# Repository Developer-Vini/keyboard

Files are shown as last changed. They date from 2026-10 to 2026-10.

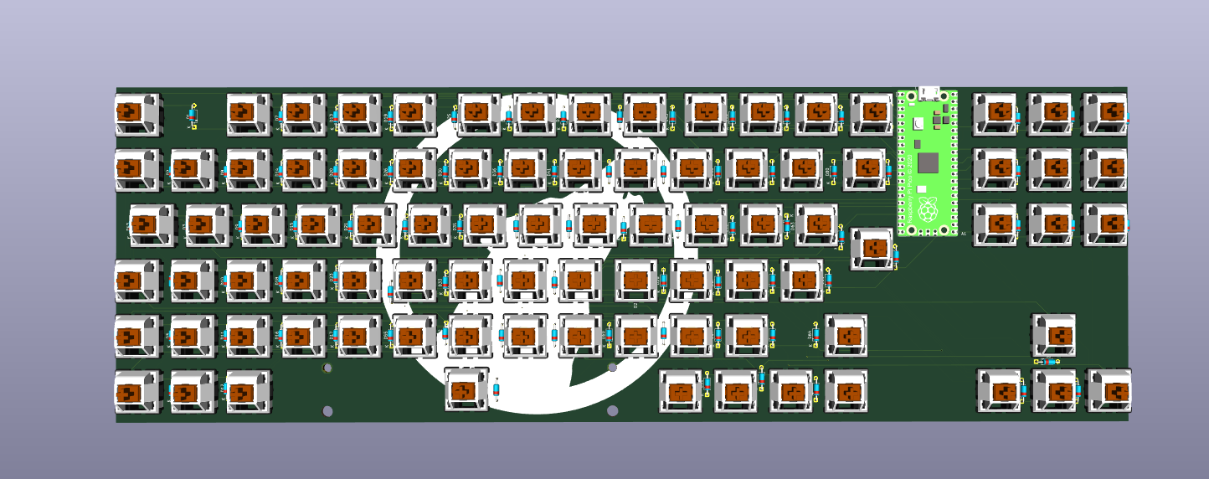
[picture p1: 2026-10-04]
docs/Images/front_pcb.png

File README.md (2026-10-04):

# Keyboard

This project is a 75% mechanical keyboard that I developed from scratch using KiCad. The idea was to create a compact, functional, and relatively simple keyboard, retaining the main keys of a conventional keyboard without taking up too much desk space.
The project was designed to be a real physical keyboard, so I didn't just focus on the visual aspect: I developed the circuit board (PCB), organized the key matrix, defined the electrical connections, and chose the necessary components so that the keyboard can be assembled and used later.

This project was going to be submitted to the Fabricate program, but I decided against it; I'll post it here instead. Because I thought halfway through, I have several other things to do, it's better not to. I didn't end up submitting it!

# Layout 
The keyboard uses a 75% layout, which retains virtually all the important functions of a full keyboard, but eliminates the spacebar and some less frequently used keys.
It has the main letter, number, and symbol keys, as well as keys such as the arrow keys, Shift, Ctrl, Alt, Enter, Backspace, and other function keys.


front_pcb

# PCB

The entire board was designed in KiCad. First, I arranged the keys according to the chosen layout and then started working on the electrical part.
The keys are part of a matrix of rows and columns. This way, it's not necessary to connect each key directly to a separate microcontroller pin. Each switch is connected to the matrix, allowing the microcontroller to identify which key was pressed.
I also added the components necessary for the correct reading of the matrix, including the diodes associated with the keys.

back_pcb
front_pcb
pcb_editor

# Scheme
general_scheme
matrix
mx_stap
raspberrypi

# Microcontroller
The keyboard has a microcontroller responsible for reading the key matrix and transforming the keystrokes into commands that the computer can interpret.


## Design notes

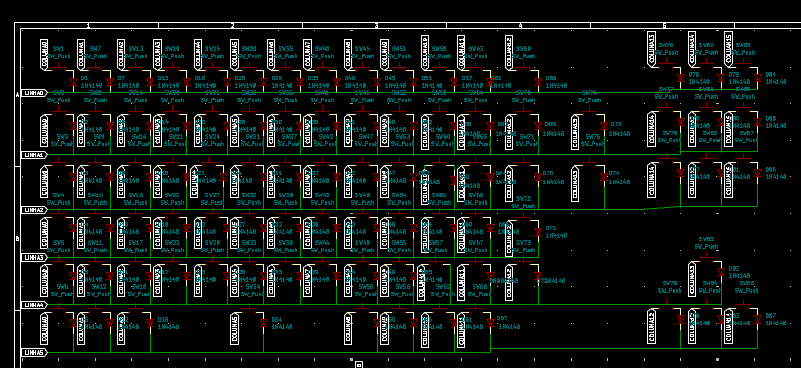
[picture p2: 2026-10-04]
docs/Images/matrix.png

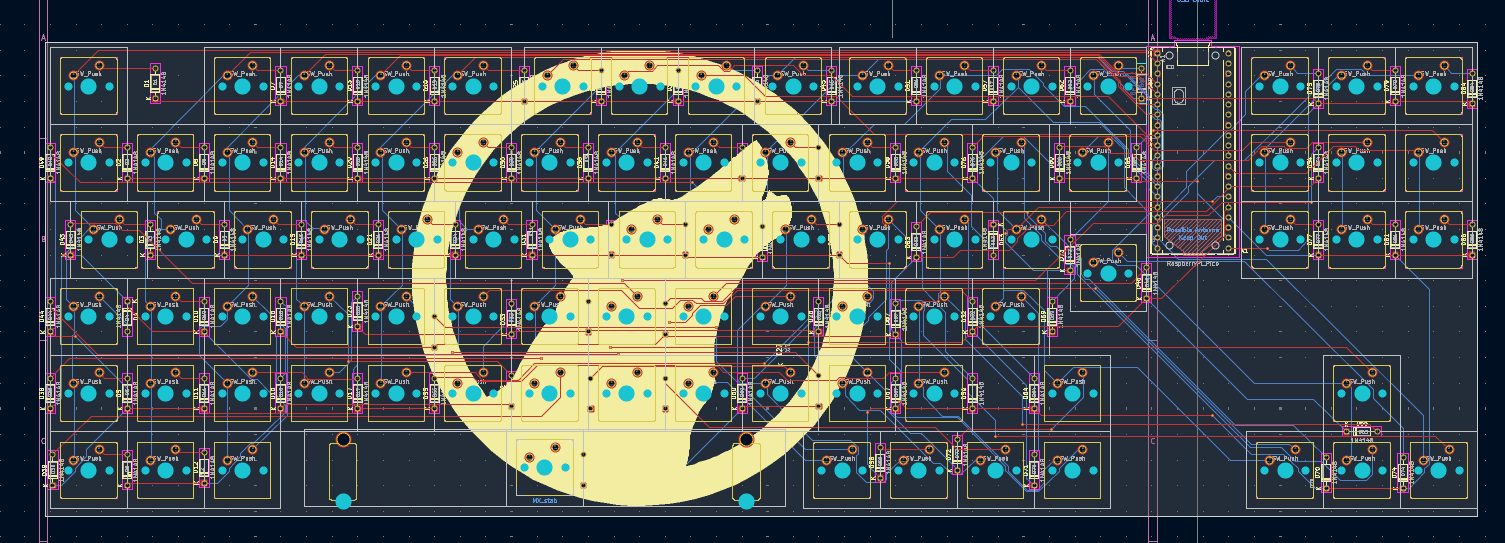
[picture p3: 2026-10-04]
docs/Images/pcb_editor.png

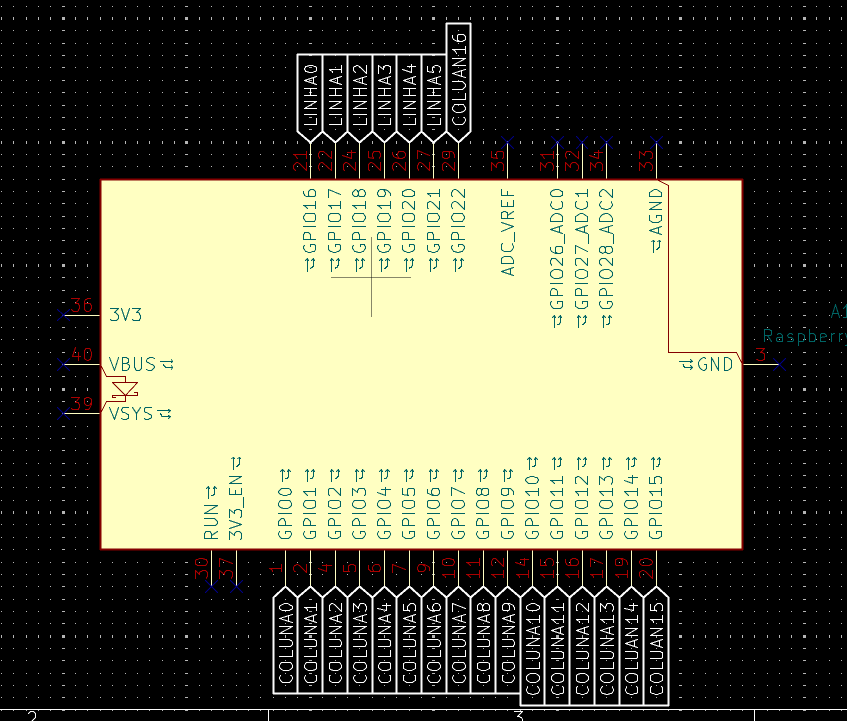
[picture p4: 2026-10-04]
docs/Images/raspberrypi.png

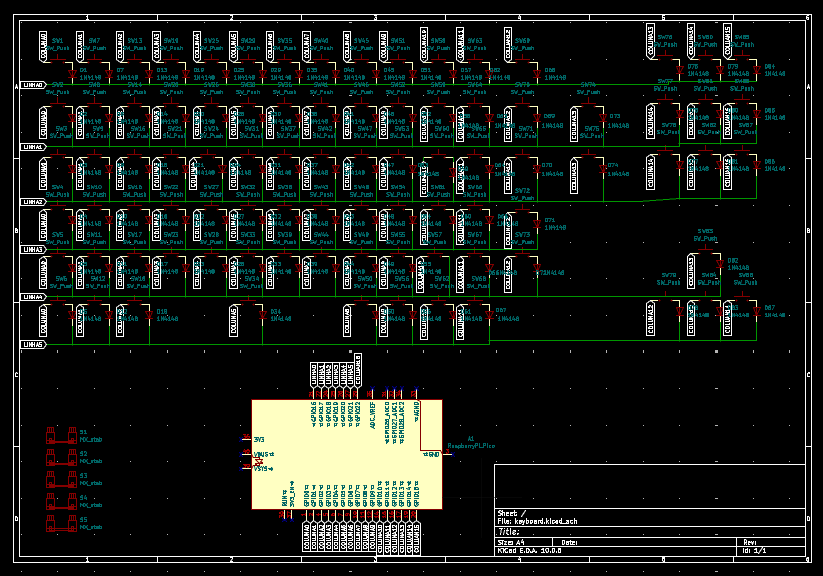
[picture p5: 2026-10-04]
docs/Images/general_scheme.png

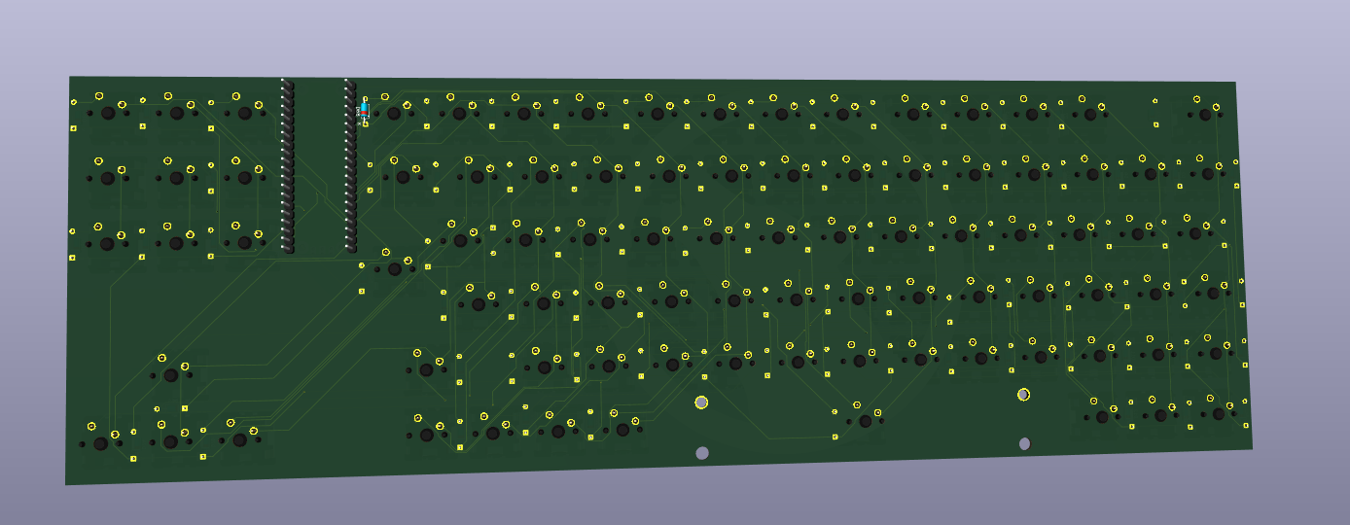
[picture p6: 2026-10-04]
docs/Images/back_pcb.png

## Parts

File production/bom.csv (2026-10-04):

Designator | Footprint | Quantity | Value | LCSC Part #
A1 | RaspberryPi_Pico_Common_THT | 1 | RaspberryPi_Pico
D1, D10, D11, D12, D13, D14, D15, D16, D17, D18, D19, D2, D20, D21, D22, D23, D24, D25, D26, D27, D28, D29, D3, D30, D31, D32, D33, D34, D35, D36, D37, D38, D39, D4, D40, D41, D42, D43, D44, D45, D46, D47, D48, D49, D5, D50, D51, D52, D53, D54, D55, D56, D57, D58, D59, D6, D60, D61, D62, D63, D64, D65, D66, D67, D68, D69, D7, D70, D71, D72, D73, D74, D75, D76, D77, D78, D79, D8, D80, D81, D82, D83, D84, D85, D86, D87, D9 | D_DO-35_SOD27_P7.62mm_Horizontal | 87 | 1N4148
S3 | STAB_MX_P_6.25u | 1 | MX_stab
SW1, SW10, SW11, SW12, SW13, SW14, SW15, SW16, SW17, SW18, SW19, SW2, SW20, SW21, SW22, SW23, SW24, SW25, SW26, SW27, SW28, SW29, SW3, SW30, SW31, SW32, SW33, SW34, SW35, SW36, SW37, SW38, SW39, SW4, SW40, SW41, SW42, SW43, SW44, SW45, SW46, SW47, SW48, SW49, SW5, SW50, SW51, SW52, SW53, SW54, SW55, SW56, SW57, SW58, SW59, SW6, SW60, SW61, SW62, SW63, SW64, SW65, SW66, SW67, SW68, SW69, SW7, SW70, SW71, SW72, SW73, SW74, SW75, SW76, SW77, SW78, SW79, SW8, SW80, SW81, SW82, SW83, SW84, SW85, SW86, SW87, SW88, SW9 | SW_MX_1u | 88 | SW_Push

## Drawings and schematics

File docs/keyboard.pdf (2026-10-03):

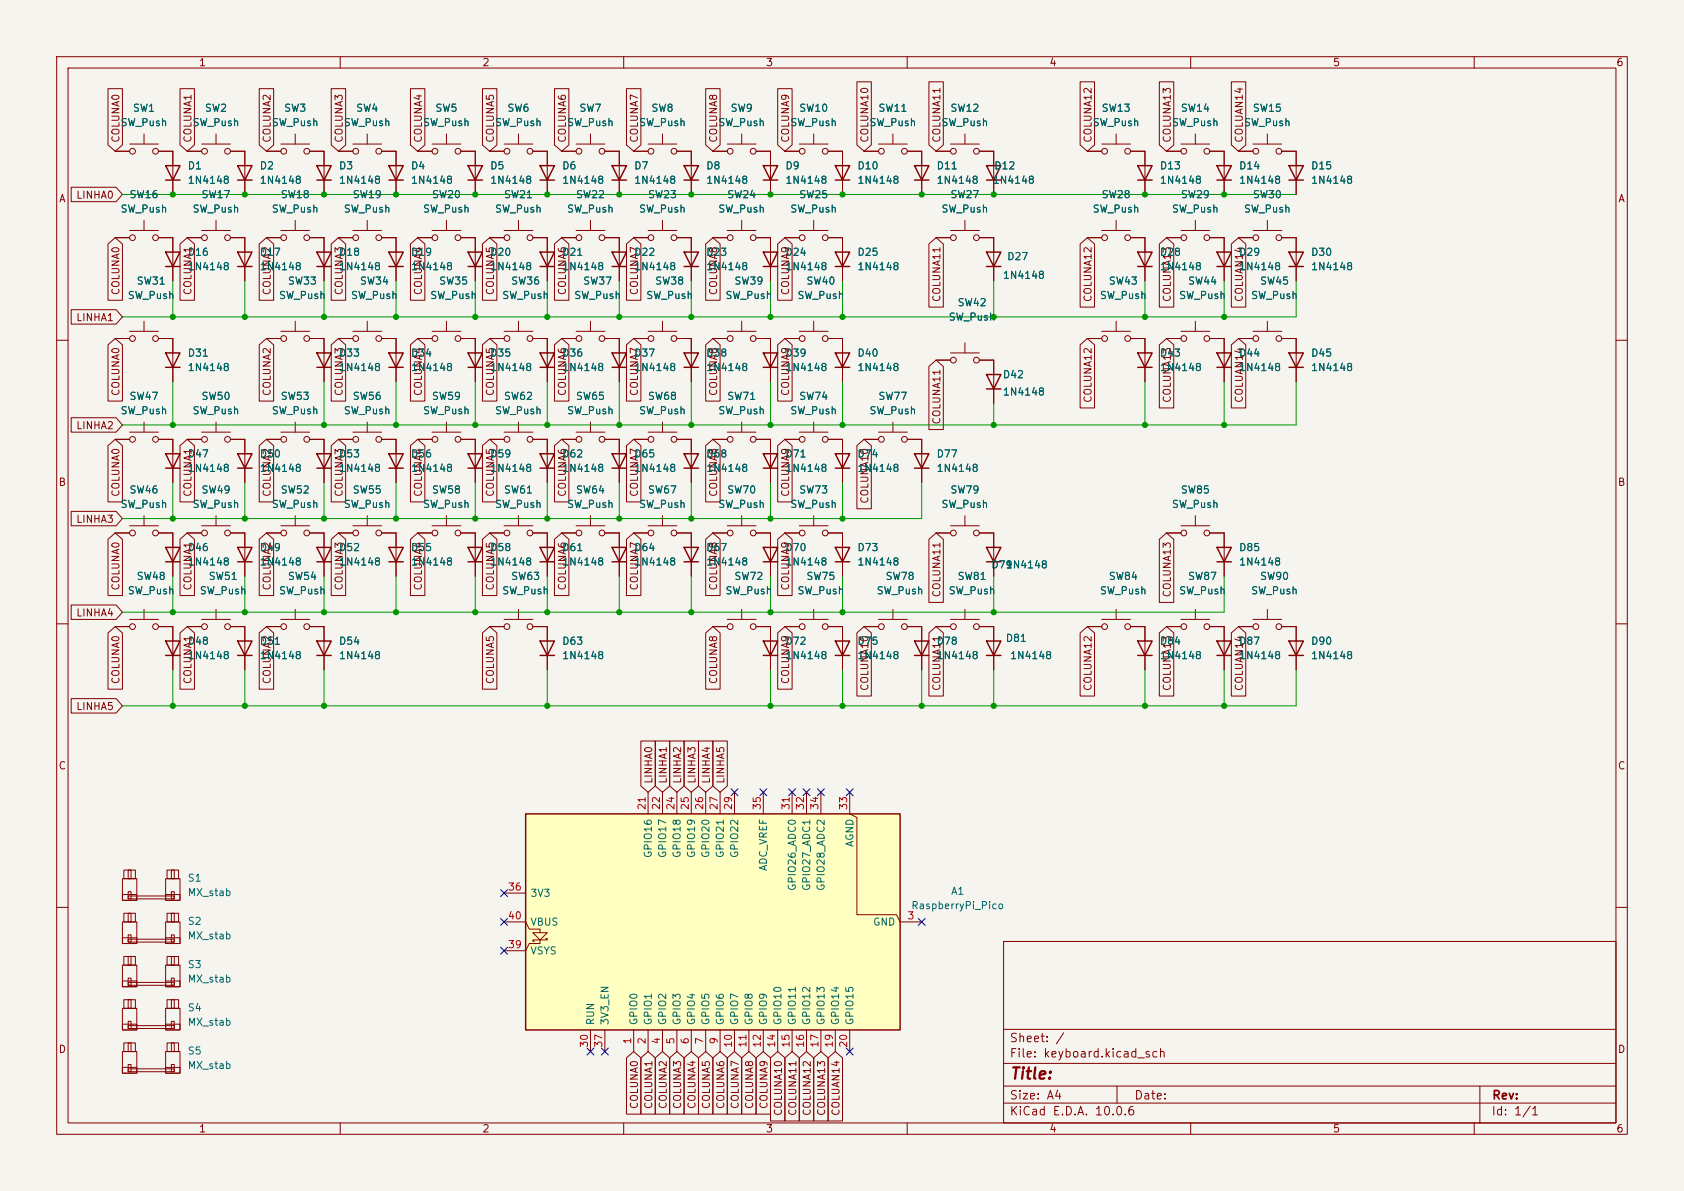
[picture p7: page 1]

Size: A4 | Rev:
KiCad E.D.A. 10.0.6 | Id: 1/1

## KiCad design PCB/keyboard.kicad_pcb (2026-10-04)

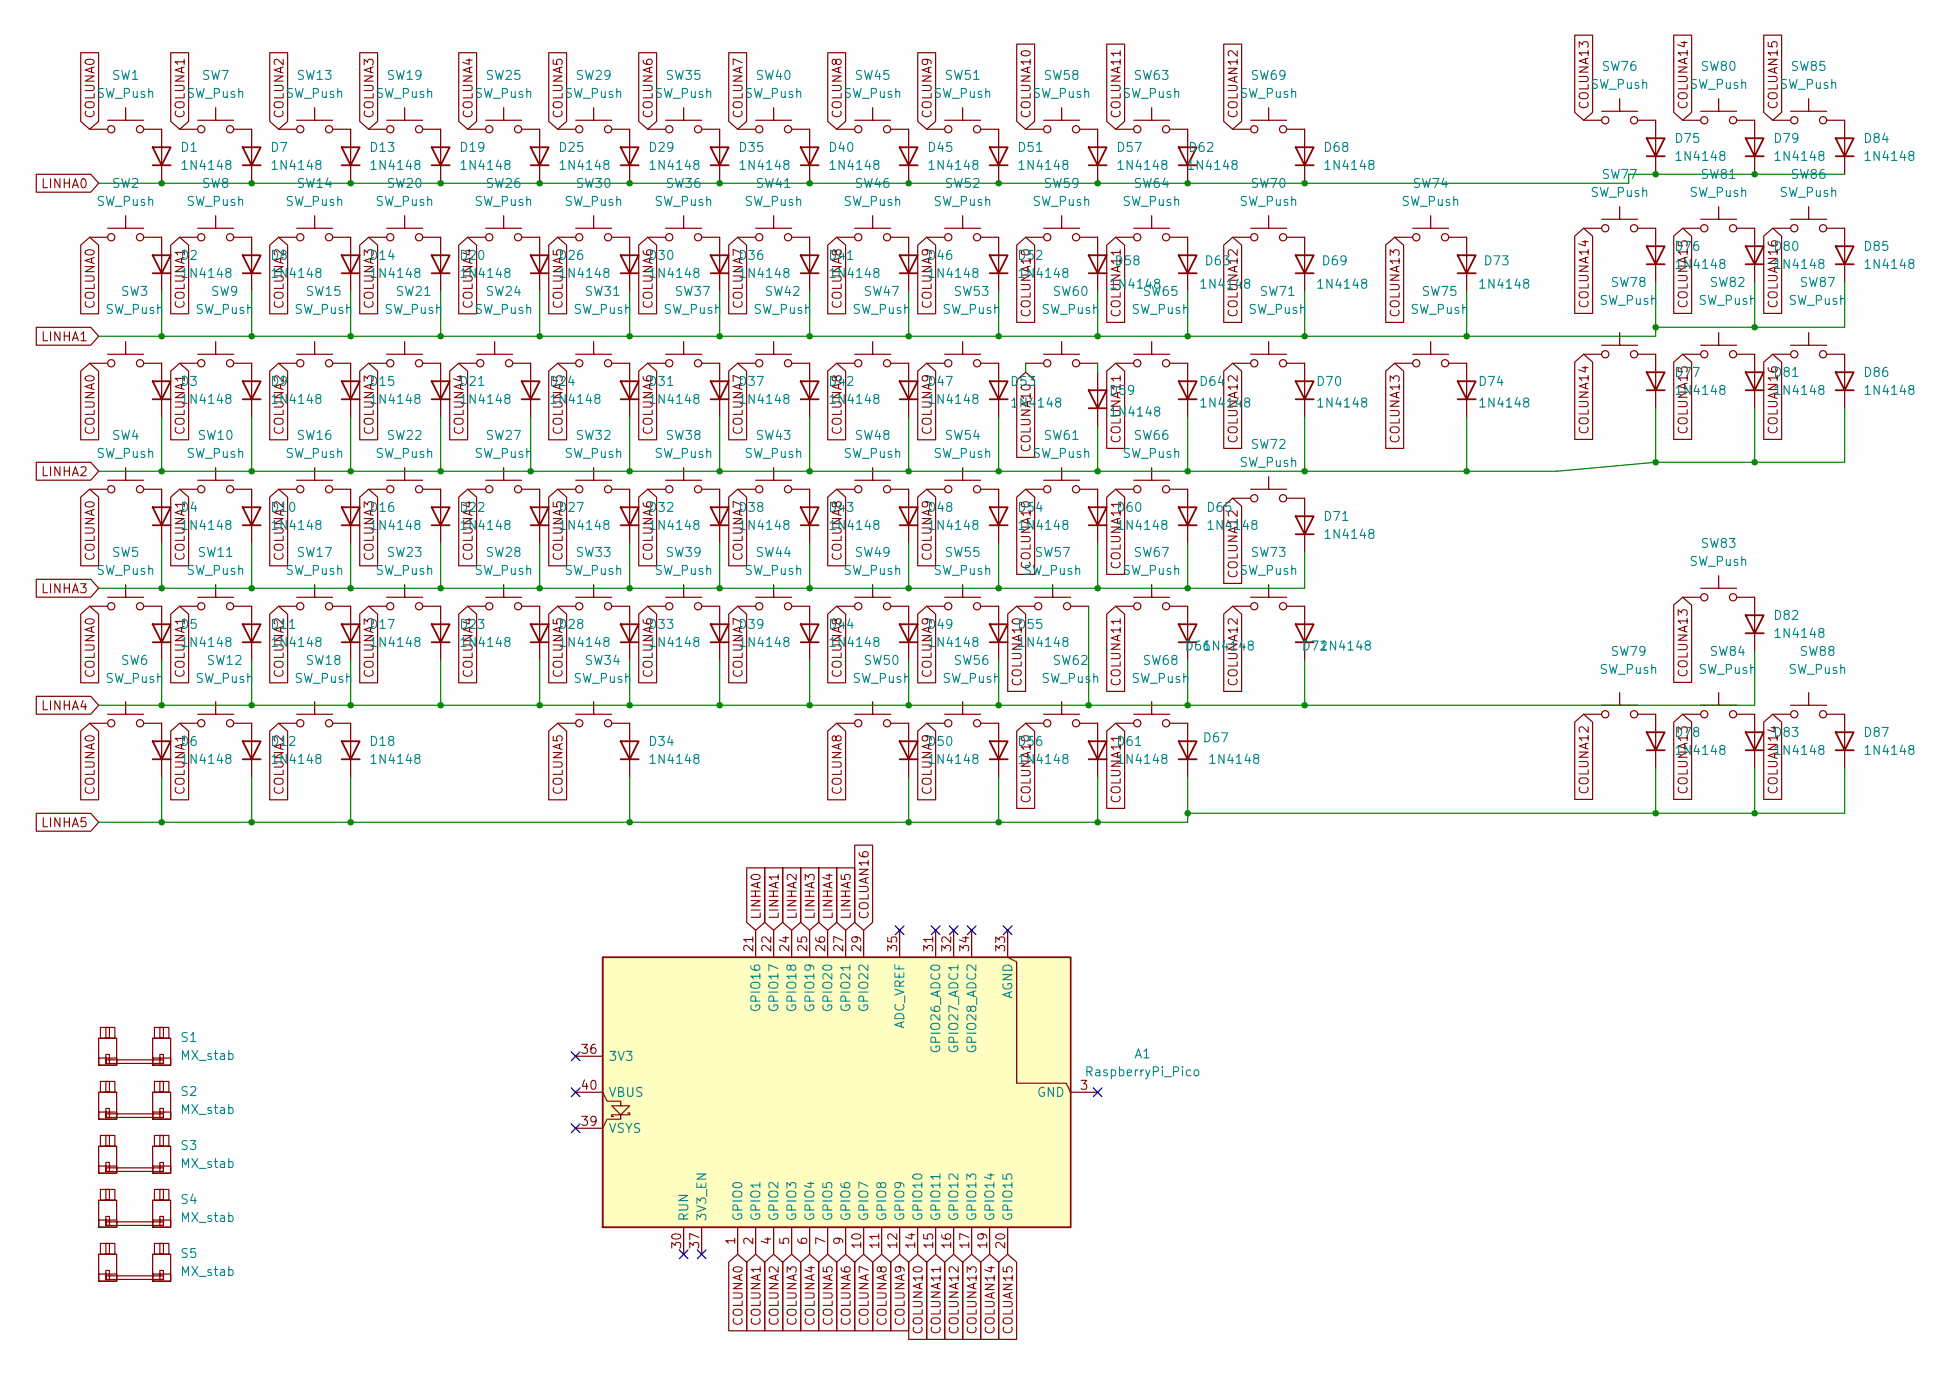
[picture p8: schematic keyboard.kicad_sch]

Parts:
A1: RaspberryPi_Pico; RaspberryPi_Pico_Common_THT
D1, D2, D3, D4, D5, D6, D7, D8, D9, D10, D11, D12, D13, D14, D15, D16, D17, D18, D19, D20, D21, D22, D23, D24, D25, D26, D27, D28, D29, D30, D31, D32, D33, D34, D35, D36, D37, D38, D39, D40, D41, D42, D43, D44, D45, D46, D47, D48, D49, D50, D51, D52, D53, D54, D55, D56, D57, D58, D59, D60, D61, D62, D63, D64, D65, D66, D67, D68, D69, D70, D71, D72, D73, D74, D75, D76, D77, D78, D79, D80, D81, D82, D83, D84, D85, D86, D87: 1N4148; D_DO-35_SOD27_P7.62mm_Horizontal
S1, S2, S3, S4, S5: MX_stab; STAB_MX_P_6.25u
SW1, SW2, SW3, SW4, SW5, SW6, SW7, SW8, SW9, SW10, SW11, SW12, SW13, SW14, SW15, SW16, SW17, SW18, SW19, SW20, SW21, SW22, SW23, SW24, SW25, SW26, SW27, SW28, SW29, SW30, SW31, SW32, SW33, SW34, SW35, SW36, SW37, SW38, SW39, SW40, SW41, SW42, SW43, SW44, SW45, SW46, SW47, SW48, SW49, SW50, SW51, SW52, SW53, SW54, SW55, SW56, SW57, SW58, SW59, SW60, SW61, SW62, SW63, SW64, SW65, SW66, SW67, SW68, SW69, SW70, SW71, SW72, SW73, SW74, SW75, SW76, SW77, SW78, SW79, SW80, SW81, SW82, SW83, SW84, SW85, SW86, SW87, SW88: SW_Push; SW_MX_1u

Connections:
COLUAN14: A1.19 (GPIO14), SW88.1
COLUAN15: A1.20 (GPIO15), SW85.1
COLUAN16: A1.29 (GPIO22), SW86.1, SW87.1
COLUNA0: A1.1 (GPIO0), SW1.1, SW2.1, SW3.1, SW4.1, SW5.1, SW6.1
COLUNA1: A1.2 (GPIO1), SW7.1, SW8.1, SW9.1, SW10.1, SW11.1, SW12.1
COLUNA2: A1.4 (GPIO2), SW13.1, SW14.1, SW15.1, SW16.1, SW17.1, SW18.1
COLUNA3: A1.5 (GPIO3), SW19.1, SW20.1, SW21.1, SW22.1, SW23.1
COLUNA4: A1.6 (GPIO4), SW24.1, SW25.1, SW26.1, SW27.1, SW28.1
COLUNA5: A1.7 (GPIO5), SW29.1, SW30.1, SW31.1, SW32.1, SW33.1, SW34.1
COLUNA6: A1.9 (GPIO6), SW35.1, SW36.1, SW37.1, SW38.1, SW39.1
COLUNA7: A1.10 (GPIO7), SW40.1, SW41.1, SW42.1, SW43.1, SW44.1
COLUNA8: A1.11 (GPIO8), SW45.1, SW46.1, SW47.1, SW48.1, SW49.1, SW50.1
COLUNA9: A1.12 (GPIO9), SW51.1, SW52.1, SW53.1, SW54.1, SW55.1, SW56.1
COLUNA10: A1.14 (GPIO10), SW57.1, SW58.1, SW59.1, SW60.1, SW61.1, SW62.1
COLUNA11: A1.15 (GPIO11), SW63.1, SW64.1, SW65.1, SW66.1, SW67.1, SW68.1
COLUNA13: A1.17 (GPIO13), SW74.1, SW75.1, SW76.1, SW83.1, SW84.1
COLUNA14: SW77.1, SW78.1, SW80.1
COLUNA15: SW81.1, SW82.1
LINHA0: A1.21 (GPIO16), D1.1 (K), D7.1 (K), D13.1 (K), D19.1 (K), D25.1 (K), D29.1 (K), D35.1 (K), D40.1 (K), D45.1 (K), D51.1 (K), D57.1 (K), D62.1 (K), D68.1 (K), D75.1 (K), D79.1 (K), D84.1 (K)
LINHA1: A1.22 (GPIO17), D2.1 (K), D8.1 (K), D14.1 (K), D20.1 (K), D26.1 (K), D30.1 (K), D36.1 (K), D41.1 (K), D46.1 (K), D52.1 (K), D58.1 (K), D63.1 (K), D69.1 (K), D73.1 (K), D76.1 (K), D80.1 (K), D85.1 (K)
LINHA2: A1.24 (GPIO18), D3.1 (K), D9.1 (K), D15.1 (K), D21.1 (K), D24.1 (K), D31.1 (K), D37.1 (K), D42.1 (K), D47.1 (K), D53.1 (K), D59.1 (K), D64.1 (K), D70.1 (K), D74.1 (K), D77.1 (K), D81.1 (K), D86.1 (K)
LINHA3: A1.25 (GPIO19), D4.1 (K), D10.1 (K), D16.1 (K), D22.1 (K), D27.1 (K), D32.1 (K), D38.1 (K), D43.1 (K), D48.1 (K), D54.1 (K), D60.1 (K), D65.1 (K), D71.1 (K)
LINHA4: A1.26 (GPIO20), D5.1 (K), D11.1 (K), D17.1 (K), D23.1 (K), D28.1 (K), D33.1 (K), D39.1 (K), D44.1 (K), D49.1 (K), D55.1 (K), D66.1 (K), D72.1 (K), D82.1 (K), SW57.2
LINHA5: A1.27 (GPIO21), D6.1 (K), D12.1 (K), D18.1 (K), D34.1 (K), D50.1 (K), D56.1 (K), D61.1 (K), D67.1 (K), D78.1 (K), D83.1 (K), D87.1 (K)
unnamed: D1.2 (A), SW1.2
unnamed: D2.2 (A), SW2.2
unnamed: D3.2 (A), SW3.2
unnamed: D4.2 (A), SW4.2
unnamed: D5.2 (A), SW5.2
unnamed: D6.2 (A), SW6.2
unnamed: D7.2 (A), SW7.2
unnamed: D8.2 (A), SW8.2
unnamed: D9.2 (A), SW9.2
unnamed: D10.2 (A), SW10.2
unnamed: D11.2 (A), SW11.2
unnamed: D12.2 (A), SW12.2
unnamed: D13.2 (A), SW13.2
unnamed: D14.2 (A), SW14.2
unnamed: D15.2 (A), SW15.2
unnamed: D16.2 (A), SW16.2
unnamed: D17.2 (A), SW17.2
unnamed: D18.2 (A), SW18.2
unnamed: D19.2 (A), SW19.2
unnamed: D20.2 (A), SW20.2
unnamed: D21.2 (A), SW21.2
unnamed: D22.2 (A), SW22.2
unnamed: D23.2 (A), SW23.2
unnamed: D24.2 (A), SW24.2
unnamed: D25.2 (A), SW25.2
unnamed: D26.2 (A), SW26.2
unnamed: D27.2 (A), SW27.2
unnamed: D28.2 (A), SW28.2
unnamed: D29.2 (A), SW29.2
unnamed: D30.2 (A), SW30.2
unnamed: D31.2 (A), SW31.2
unnamed: D32.2 (A), SW32.2
unnamed: D33.2 (A), SW33.2
unnamed: D34.2 (A), SW34.2
unnamed: D35.2 (A), SW35.2
unnamed: D36.2 (A), SW36.2
unnamed: D37.2 (A), SW37.2
unnamed: D38.2 (A), SW38.2
unnamed: D39.2 (A), SW39.2
unnamed: D40.2 (A), SW40.2
unnamed: D41.2 (A), SW41.2
unnamed: D42.2 (A), SW42.2
unnamed: D43.2 (A), SW43.2
unnamed: D44.2 (A), SW44.2
unnamed: D45.2 (A), SW45.2
unnamed: D46.2 (A), SW46.2
unnamed: D47.2 (A), SW47.2
unnamed: D48.2 (A), SW48.2
unnamed: D49.2 (A), SW49.2
unnamed: D50.2 (A), SW50.2
unnamed: D51.2 (A), SW51.2
unnamed: D52.2 (A), SW52.2
unnamed: D53.2 (A), SW53.2
unnamed: D54.2 (A), SW54.2
unnamed: D55.2 (A), SW55.2
unnamed: D56.2 (A), SW56.2
unnamed: D57.2 (A), SW58.2
unnamed: D58.2 (A), SW59.2
unnamed: D59.2 (A), SW60.2
unnamed: D60.2 (A), SW61.2
unnamed: D61.2 (A), SW62.2
unnamed: D62.2 (A), SW63.2
unnamed: D63.2 (A), SW64.2
unnamed: D64.2 (A), SW65.2
unnamed: D65.2 (A), SW66.2
unnamed: D66.2 (A), SW67.2
unnamed: D67.2 (A), SW68.2
unnamed: D68.2 (A), SW69.2
unnamed: D69.2 (A), SW70.2
unnamed: D70.2 (A), SW71.2
unnamed: D71.2 (A), SW72.2
unnamed: D72.2 (A), SW73.2
unnamed: D73.2 (A), SW74.2
unnamed: D74.2 (A), SW75.2
unnamed: D75.2 (A), SW76.2
unnamed: D76.2 (A), SW77.2
unnamed: D77.2 (A), SW78.2
unnamed: D78.2 (A), SW79.2
unnamed: D79.2 (A), SW80.2
unnamed: D80.2 (A), SW81.2
unnamed: D81.2 (A), SW82.2
unnamed: D82.2 (A), SW83.2
unnamed: D83.2 (A), SW84.2
unnamed: D84.2 (A), SW85.2
unnamed: D85.2 (A), SW86.2
unnamed: D86.2 (A), SW87.2
unnamed: D87.2 (A), SW88.2

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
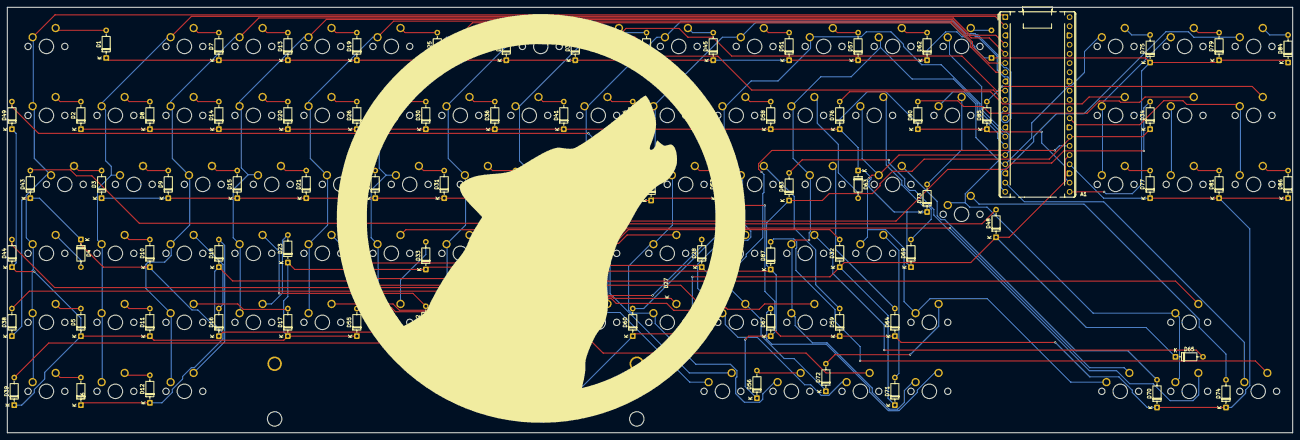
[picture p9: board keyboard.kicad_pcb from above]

Board: 2 copper layers, 355.0 x 117.5 mm, 177 parts (1 on the bottom side), 112 nets.

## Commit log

2026-10-03 docs: add new images
    [keyboard.kicad_sch]
2026-10-04 feat: new images project and finished pcb
    [keyboard.kicad_pcb, keyboard.kicad_sch, temp-freerouting.dsn]
2026-10-04 add folder production
    [bom.csv, designators.csv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]
2026-10-04 Add README for custom 75% mechanical keyboard project
    This README provides an overview of a custom 75% mechanical keyboard project, detailing its design, layout, PCB, schematics, and microcontroller functionality.
2026-10-26 feat: update README with parts used and BOM
    Added parts list and BOM for keyboard project.
2026-10-26 feat: update README with case images and layout details
    Added case images and updated layout section in README.
2026-10-26 feat: print the keys pressed
